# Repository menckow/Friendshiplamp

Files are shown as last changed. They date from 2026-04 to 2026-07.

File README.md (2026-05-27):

# Friendship Lamp (V2.3 — Family Schema)

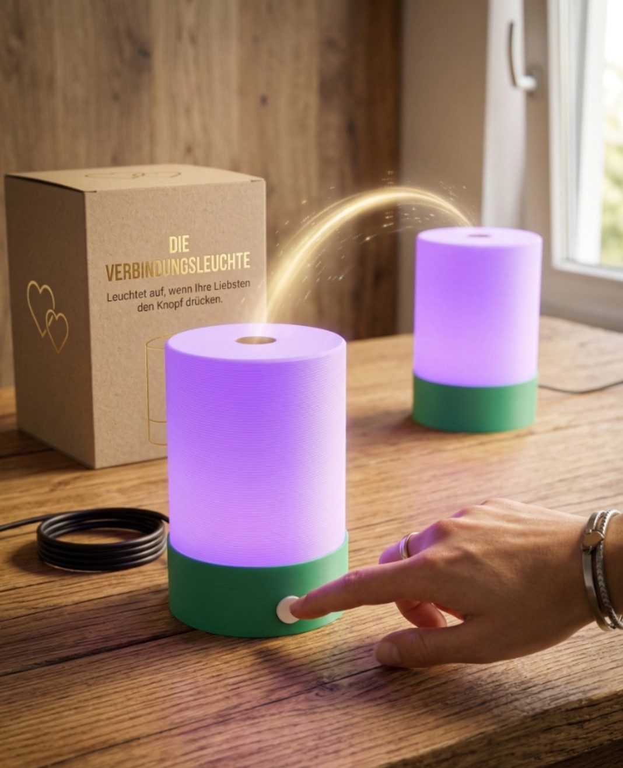
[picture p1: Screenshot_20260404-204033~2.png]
Friendship Lamp


The **Friendship Lamp** is an ESP32-based ambient light that connects friends through synchronized colors. When one person touches their lamp, all connected lamps across the world pulse in their unique identity color via MQTT.

Version **V2.3** introduces the **family circle schema (v2)** — a single lamp can belong to multiple family circles simultaneously, and the central Device Manager Dashboard groups all devices by family.

## 🚀 Key Features

*   **Modular Architecture**: Clean separation of hardware control, network logic, and configuration.
*   **Family Circles (v2 Schema)**: Configure one or more `Familienkreise` (comma-separated) per lamp. The lamp publishes button presses to every family it belongs to and receives signals from all of them. Multi-membership is supported.
*   **Source-Aware Signaling**: Each signal carries a `sender_type` field. Lamps ignore signals originating from boxes (so a box's motion sensor doesn't wake the lamp), while boxes show the lamp's color in a special complementary-LED mode when a lamp triggered the signal.
*   **Local Button Feedback**: Pressing the button lights the lamp itself in the identity color — visual confirmation that the press was registered, independent of the MQTT round-trip.
*   **Robust OTA Updates (two channels)**:
    *   **MQTT-triggered OTA**: per-device (`fl/device/<id>/update/trigger`), per-family (`fl/family/<f>/update/trigger/lamp`), or global (`fl/_global/update/trigger/lamp`). All with 32-character **MD5 validation** and dynamic LED progress bar.
    *   **Web Upload OTA**: Browse to the configuration page and upload a `.bin` directly; the lamp validates MD5 (optional), writes via chunked `Update.write()` and reboots automatically.
*   **Smart Security**: Built-in standard Root CA (ISRG Root X1) for seamless out-of-the-box support for HiveMQ and other secure public brokers—no manual certificate pasting required.
*   **Advanced Lighting Engine**: Smooth 32-bit gamma correction with effects like *Fade, Rainbow, Breathe, Fire, Comet,* and more.
*   **Intuitive Web Configuration & Remote Control**:
    *   **Captive Portal**: Mobile-friendly local portal for Wi-Fi setup, MQTT credentials, family-circle assignment, and hardware calibration.
    *   **Dedicated Web App**: A standalone modern [Web App](manager/Friendshiplamp_Web_App_V4_Final.html) for remote triggering of the lamp with custom color and **selectable effects** (Fade, Wipe, Chase, Rainbow, etc.).
*   **Smart Hardware Control**:
    *   **Capacitive Touch**: For On/Off and continuous brightness dimming.
    *   **Potentiometer**: Direct local color selection.
    *   **Button**: Sending the pulse color to friends.
*   **Night Mode (Do Not Disturb)**: NTP-synced, scheduled quiet hours configurable via the Web UI to keep the room completely dark and suppress incoming color flashes during sleep.

## 🛠️ Hardware Requirements

*   **Microcontroller**: ESP32 Dev Kit C or ESP32-S3.
*   **LEDs**: WS2812B (NeoPixel) Ring or Strip.
*   **Inputs**:
    *   1x Potentiometer (Analog)
    *   1x Momentary Button
    *   1x Capacitive Touch sensor (or a simple wire to a touch pin)

### Default Pinout (Configurable)

| Component | ESP32 Pin |
| --- | --- |
| NeoPixel DIN | GPIO 13 |
| Potentiometer Signal| GPIO 34 |
| Send Button | GPIO 4 |
| Touch Sensor | GPIO 32 |

## 💻 Setup & Installation

### 1. Build & Upload
This project is professionally managed using **PlatformIO**. 
1.  Clone the repository.
2.  Open the folder in VS Code with the PlatformIO extension installed.
3.  Click **Build** and then **Upload**.

### 2. First-Time Configuration
1.  If no Wi-Fi is configured, the lamp will pulse **purple** and open a Wi-Fi hotspot named `Freundschaftslampe-Setup`.
2.  Connect to the hotspot (Password: `12345678`).
3.  Your browser should open `http://192.168.4.1` automatically.
4.  Enter your home Wi-Fi details and MQTT broker credentials.
    *   *Tip: If using HiveMQ, simply check the "Use Standard Root-CA" box.*
5.  **Enter Family Circles** (comma-separated list, e.g. `schmidt,lieblings`). The lamp will subscribe to one signal topic per family and fan out its own button presses to all of them. Whitespace and case are normalized automatically.

## 📡 MQTT Integration & Monitoring

The project works with a central [Device Manager Dashboard](manager/dashboard_secure.html), which groups all devices by family circle and shows a green `v2` pill next to family-aware devices.

### Topic schema (v2)

| Purpose | Topic | Retained |
|---|---|---|
| Family signal (publisher + subscriber) | `fl/family/<familyId>/signal` | no |
| Device status (JSON) | `fl/device/<deviceId>/status` | **yes** |
| OTA per single device | `fl/device/<deviceId>/update/trigger` | no |
| OTA per family (lamps only) | `fl/family/<familyId>/update/trigger/lamp` | no |
| Global emergency OTA (lamps only) | `fl/_global/update/trigger/lamp` | no |
| OTA progress backchannel | `fl/device/<deviceId>/update/status` | no |

### Status payload (retained JSON)

```json
{
  "type": "lamp",
  "fw": "V2.3.0",
  "state": "online",
  "color": "#FFAA00",
  "families": ["schmidt", "lieblings"]
}
```

### Signal payload (on button press)

```json
{
  "client_id": "Schmidt-Wohnzimmer",
  "sender_type": "lamp",
  "color": "#FFAA00",
  "effect": "fade",
  "duration": 30000,
  "ts": 1716729600
}
```

The receiving devices apply a **self-filter** (ignore messages where `client_id` matches their own ID, important for multi-family membership) and an **NTP age filter** (older than 60 seconds → ignored, to prevent retained messages from re-triggering after reconnect).

### OTA payload

```json
{
  "url": "https://your-server.com/firmware.bin",
  "version": "V2.3.1",
  "md5": "b3e3e3b3e3e3b3e3e3b3e3e3b3e3e3b3",
  "target_type": "lamp"
}
```

`target_type` is optional defense-in-depth — devices verify it matches their own type before accepting the update.

### Web Upload OTA

Open the lamp's configuration page and use the **Firmware-Update** section to upload a `.bin` file directly. The lamp validates MD5 (optional 32-char hex), writes the firmware, and reboots automatically. The dashboard sees status changes via MQTT during the upload.

## 📄 License & Credits
Developed for the community. Feel free to fork and enhance!

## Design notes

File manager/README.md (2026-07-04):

# Manager — Browser-basierte Tools

In diesem Verzeichnis liegen zwei eigenständige HTML-Werkzeuge, die direkt im Browser laufen — kein Webserver, keine Installation. Beide Dateien öffnest Du per Doppelklick oder hostest sie statisch (z.B. GitHub Pages).

| Datei | Zweck |
|---|---|
| [`dashboard_secure.html`](dashboard_secure.html) | **Device Manager Dashboard** — zentrale Übersicht aller Lampen + Boxen, gruppiert nach Familienkreis, mit OTA-Steuerung. |
| [`Friendshiplamp_Web_App_V4_Final.html`](Friendshiplamp_Web_App_V4_Final.html) | Standalone-Remote für eine einzelne Lampe — Farbe und Effekt manuell auslösen. |

---

## 📊 Device Manager Dashboard

`dashboard_secure.html` ist die Leitstelle für alle Geräte in Deiner MQTT-Topologie. Es verbindet sich per **MQTT-over-WebSockets (TLS)** mit Deinem Broker und abonniert sowohl das alte v1-Schema als auch das neue v2-Familien-Schema parallel — Du siehst also Bestand und migrierte Geräte gleichzeitig.

### Login

Beim Öffnen erscheint eine Login-Maske. Trage ein:

* **MQTT Broker** — z.B. `xxx.s1.eu.hivemq.cloud` (ohne `wss://`, ohne Trailing-Slash)
* **Port** — `8884` für HiveMQ Cloud WebSockets (`8883` wird automatisch zu `8884` korrigiert, weil Browser TCP-MQTT nicht direkt sprechen können)
* **Username / Passwort** — die MQTT-Credentials Deines Brokers

Broker, User und Port werden für den nächsten Besuch im `localStorage` gespeichert. Das **Passwort nicht** — es bleibt nur in der Sitzung.

### Geräteliste

Sobald die Verbindung steht, abonniert das Dashboard:

* `+/status/#` (altes v1-Schema, z.B. `freundschaftslampe/status/<id>` und `zwitscherbox/status/<id>`)
* `fl/device/+/status` (v2-Schema mit JSON-Payload)
* `fl/device/+/update/status` (v2-OTA-Backchannel)

Jede empfangene Status-Nachricht wird zur Tabelle zugefügt oder aktualisiert. Geräte erscheinen **gruppiert nach Familienkreis** — v2-Geräte landen in der Gruppe ihrer im Payload genannten `families`, mehrfach falls in mehreren Kreisen. Geräte ohne Familienzuordnung (alle v1-Geräte und v2-Geräte ohne `families[]`) landen in der Sammelgruppe **„Bestand (altes Schema, ohne Familienzuordnung)"**.

Jede Gerätezeile zeigt:

| Spalte | Bedeutung |
|---|---|
| ID | Identitätsfarbe als Kreis + Client-ID + Schema-Pille (grün `v2` oder gelb `v1`) |
| Typ | `Lampe`, `Box (V6)`, `Box (A1S)` oder `Box (v1)`. Die beiden Box-Varianten brauchen unterschiedliche Firmware-Binaries — der Typ ergibt sich aus dem `type`-Feld der Status-JSON (`lamp`, `box`, `box-a1s`). |
| Version | Firmware-Version aus `fw` (v2) bzw. erstem Feld des `:`-Payload (v1) |
| Status | `online` / `offline` / Update-Status (gelb hinterlegt wenn `update` im Text) |
| Aktion | **Update**-Button für Einzelgerät |

### OTA-Karten

Im Grid unter der Tabelle gibt es vier Update-Karten:

| Karte | Zielgruppe | Topic |
|---|---|---|
| **Update: Lampen (v1)** | Alle v1-Lampen | `freundschaftslampe/update/trigger` |
| **Update: Zwitscherboxen (v1)** | Alle v1-Boxen | `zwitscherbox/update/trigger` |
| **Update: Pro Familie (v2)** | Lampen, V6-Boxen oder A1S-Boxen einer Familie | `fl/family/<id>/update/trigger/<type>` |
| **Update: Globaler Notfall-Push (v2)** | Alle Lampen, V6-Boxen oder A1S-Boxen | `fl/_global/update/trigger/<type>` |

`<type>` ist `lamp`, `box` (V6) oder `box-a1s` (A1S). Die drei Geräte-Typen brauchen unterschiedliche Firmware-Images — deshalb gibt es bewusst kein „Alles auf einmal", sondern einen Typ-Selektor in jeder Karte. Das Familien-Dropdown füllt sich automatisch aus den gesehenen Geräten — also: wenn keine Familie in der Liste, hat noch keine v2-Box/-Lampe sich gemeldet.

Jeder Update-Vorgang fragt vorher per Modal um Bestätigung und zeigt das tatsächlich verwendete Topic an.

### Einzel-Update

Klick auf **Update** in einer Gerätezeile öffnet die Bestätigung. Das Topic wird schema-bewusst gewählt:

* **v2-Geräte** → `fl/device/<id>/update/trigger`
* **v1-Lampen** → `freundschaftslampe/update/trigger/<id>` (Per-Device-Topic, das die migrierte Lampen-FW seit der ersten Phase abonniert)
* **v1-Boxen** → `zwitscherbox/update/trigger` mit `target: <id>` im Payload (Broadcast-Filter, der seit jeher auch von alter Box-FW respektiert wird — daher universell kompatibel)

Die URL, Version und MD5 werden aus der passenden v1-Karte oder den Familien-/Global-Feldern gezogen.

### Payload-Format

Alle OTA-Triggers verwenden das gleiche JSON:

```json
{
  "url": "https://your-server.com/firmware.bin",
  "version": "V2.3.1",
  "md5": "b3e3e3b3e3e3b3e3e3b3e3e3b3e3e3b3"
}
```

Bei v1-Box-Einzel-Updates kommt zusätzlich `"target": "<deviceId>"` dazu, damit nur die adressierte Box updatet. Bei v2-Topics nicht nötig — das Topic adressiert direkt.

### Sicherheits-Tipp

Das Dashboard ist eine reine Client-HTML — alle Credentials und Befehle laufen über Deinen Browser zum MQTT-Broker. Wenn Du das auf einem öffentlich erreichbaren Server hostest:

* Stelle sicher, dass nur autorisierte Personen Zugriff haben (z.B. via Reverse-Proxy mit Basic Auth).
* Nutze einen MQTT-User mit ACLs, die nur auf die nötigen Topics zugreifen können.
* Der WebSocket geht über `wss://` (TLS) — der Broker muss das unterstützen (HiveMQ Cloud tut das).

---

## 💡 Standalone Lamp Remote

`Friendshiplamp_Web_App_V4_Final.html` ist ein simples Remote-Frontend für eine **einzelne** Lampe. Du wählst Farbe, Effekt und Dauer, und das Tool publisht einen einzelnen Signal-Payload an das Signal-Topic. Nutzbar als „Lampe ohne Button" — z.B. wenn Du jemandem aus der Ferne ein bestimmtes Licht-Signal schicken willst.

Hinweis: Dieses Werkzeug stammt aus der v1-Ära und schreibt aktuell ans alte `mqttTopic`. Für v2 müsste es entsprechend auf `fl/family/<id>/signal` umgestellt werden — das ist noch nicht passiert. Wenn Du das brauchst, sag Bescheid, dann ziehen wir das Tool ebenfalls nach.

---

## Lokal öffnen vs. hosten

Beide HTML-Dateien sind self-contained (CDN-Abhängigkeit: `mqtt.js` für WebSocket-MQTT). Du kannst sie:

* **Doppelklicken** und im Browser direkt benutzen — funktioniert für die meisten modernen Browser.
* **Statisch hosten** (GitHub Pages, Caddy, Nginx, ein S3-Bucket usw.) — empfohlen, wenn Du sie öfter brauchst, weil sich Bookmarks/`localStorage` so sauber zuordnen lassen.

Kein Build-Schritt nötig.

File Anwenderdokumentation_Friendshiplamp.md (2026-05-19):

# 🌟 Freundschaftslampe — Anwenderdokumentation

**Version 2.2** · Stand: 2026-05

Diese Lampe verbindet dich über das Internet mit deinen Liebsten. Wenn du sie berührst und auf den Senden‑Knopf drückst, leuchten die verbundenen Lampen weltweit in deiner persönlichen Farbe auf — und umgekehrt.

---

## Inhalt

1. [Lieferumfang & Hardware-Übersicht](#1-lieferumfang--hardware-übersicht)
2. [Statusfarben (was die Lampe dir sagt)](#2-statusfarben-was-die-lampe-dir-sagt)
3. [Erstinbetriebnahme](#3-erstinbetriebnahme-schritt-für-schritt)
4. [Bedienung im Alltag](#4-bedienung-im-alltag)
5. [Konfigurations-Referenz (Webinterface)](#5-konfigurations-referenz-webinterface)
6. [Lichteffekte](#6-lichteffekte)
7. [Ruhemodus / Nicht stören](#7-ruhemodus--nicht-stören)
8. [Sicherheit (Admin-Passwort & TLS)](#8-sicherheit-admin-passwort--tls)
9. [Dashboard & OTA-Updates](#9-dashboard--ota-updates)
10. [Werkseinstellungen / Reset](#10-werkseinstellungen--reset)
11. [Troubleshooting](#11-troubleshooting)

---

## 1. Lieferumfang & Hardware-Übersicht

Eine vollständige Freundschaftslampe besteht aus:

| Komponente | Beschreibung |
|---|---|
| **ESP32 Dev Kit C** | Der "Kopf" der Lampe — WLAN-fähiger Mikrocontroller |
| **WS2812B / NeoPixel Ring** | Der Leuchtring (typisch 16, 24 oder 40 LEDs) |
| **Touch-Pad** | Eine kapazitive Fläche oder ein Draht an GPIO 32 |
| **Drehregler (Potentiometer)** | Für die lokale Farbauswahl |
| **Taster** | Zum Senden eines Signals |
| **Netzteil** | 5 V, mindestens 2 A empfohlen |
| **3D-gedrucktes Gehäuse** | siehe `lamp/Freundschaftslampe.stl` |

### Standard-Pinbelegung

| Funktion | ESP32-Pin |
|---|---|
| NeoPixel Daten (DIN) | GPIO 13 |
| Potentiometer (Signal) | GPIO 34 |
| Senden-Taster | GPIO 4 |
| Touch-Sensor | GPIO 32 |

> Hinweis Hardware: Für eine stabile Versorgung empfiehlt sich ein **Stützkondensator (≥ 470 µF)** parallel zur 5‑V‑Versorgung des LED‑Rings und ein **Vorwiderstand (~330–470 Ω)** seriell in der Datenleitung zwischen ESP32 und dem ersten Pixel. Beides ist im aktuellen Aufbau bereits vorgesehen.

---

## 2. Statusfarben (was die Lampe dir sagt)

| Lichtmuster | Bedeutung |
|---|---|
| 🟣 **Violett/Lila pulsierend** | Setup‑Modus: kein WLAN konfiguriert oder Heim‑WLAN nicht erreichbar |
| ⚪ **Kurz aufleuchten beim Start** | Boot abgeschlossen, Lampe startet ihre Dienste |
| 🎨 **Farbpuls in fremder Farbe** | Du hast ein Signal von einer befreundeten Lampe empfangen |
| 💡 **Konstantes Leuchten in deiner Farbe** | Normalbetrieb, Lampe ist eingeschaltet |
| 🚫 **Komplett dunkel** | Lampe ist über Touch ausgeschaltet ODER Ruhemodus aktiv |
| 🟢 **Fortschrittsbalken um den Ring** | Firmware‑Update (OTA) läuft — bitte nicht ausschalten |

---

## 3. Erstinbetriebnahme (Schritt für Schritt)

### 3.1 Strom anschließen

1. Verbinde die Lampe per USB‑Kabel mit dem mitgelieferten 5‑V‑Netzteil.
2. Nach ca. 5 Sekunden sollte die Lampe **violett** pulsieren — das ist der Setup‑Modus.

### 3.2 Mit der Lampe verbinden

1. Öffne auf deinem Smartphone oder Computer die **WLAN‑Einstellungen**.
2. Wähle das Netzwerk **`Freundschaftslampe-Setup`**.
3. Gib das Passwort ein: **`12345678`**
4. Normalerweise öffnet sich automatisch ein Konfigurationsfenster (Captive Portal).
   Falls nicht: Browser öffnen und **`http://192.168.4.1`** aufrufen.

### 3.3 Heim-WLAN eintragen

1. Im Abschnitt **WLAN‑Einstellungen** auf „Verfügbare WLANs" klicken — die Lampe scannt automatisch die Umgebung.
2. Dein Heim‑WLAN auswählen oder die SSID manuell eintragen.
3. WLAN‑Passwort eingeben.

### 3.4 MQTT-Broker eintragen

MQTT ist der Nachrichtendienst, über den die Lampen miteinander sprechen. Du brauchst die Zugangsdaten zu einem MQTT‑Broker.

**Empfohlen für Einsteiger:** [HiveMQ Cloud](https://www.hivemq.com/) — kostenlos für kleine Mengen, TLS standardmäßig aktiv.

| Feld | Beispiel | Bemerkung |
|---|---|---|
| MQTT Broker | `xxx.s2.eu.hivemq.cloud` | Hostname ohne `https://` |
| MQTT Port | `8883` | bei TLS, sonst `1883` |
| MQTT mit TLS/SSL | ✅ aktiviert | Empfohlen |
| Standard Root‑CA nutzen | ✅ aktiviert | Funktioniert mit HiveMQ und allen Let's‑Encrypt‑Brokern |
| MQTT Client ID | `Tom-Wohnzimmer` | Eindeutiger Name dieser Lampe |
| MQTT Topic | `freundschaftslampe/familie-meier` | Gleiches Topic für alle Lampen, die einander erreichen sollen |
| Benutzername / Passwort | (deine HiveMQ-Credentials) | |

> Wichtig: **Alle Lampen, die sich gegenseitig anleuchten sollen, müssen dasselbe Topic verwenden.**

### 3.5 Identität festlegen

Im Abschnitt **Lampen‑Einstellungen**:

* **Anzahl LEDs** auf den realen Wert deines Rings setzen (z. B. `16`, `24` oder `40`).
* **Touch‑Empfindlichkeit** vorerst auf `40` lassen (Standardwert).
* **Identitätsfarbe** wählen — diese Farbe sehen deine Freunde, wenn du ein Signal sendest.
* **Lichteffekt** wählen (siehe Kapitel 6).
* **Anzeigedauer** in Sekunden setzen (Standard: 10 s).

### 3.6 Admin-Passwort setzen

Im obersten Abschnitt **Administrator** trägst du ein **Webinterface-Passwort** ein. Dieses brauchst du später, wenn du die Lampe von deinem Heim‑WLAN aus konfigurieren willst. Lässt du das Feld leer (oder schreibst `none`), ist das Webinterface ohne Passwort erreichbar.

### 3.7 Speichern & Neustarten

Klicke unten auf **Speichern & Neustarten**.

* Die Lampe trennt das Setup‑Netzwerk und startet neu.
* Nach erfolgreichem Verbinden ist das violette Pulsieren weg.
* Sie ist nun bereit. 🎉

---

## 4. Bedienung im Alltag

### 👆 Touch-Sensor — Ein/Aus & Helligkeit

| Geste | Funktion |
|---|---|
| **Kurz tippen** (< 1 s) | Lampe **ein/aus** schalten |
| **Lang halten** (> 1 s) | **Helligkeit** stufenlos dimmen. Loslassen, wenn die Wunschhelligkeit erreicht ist. Bei der nächsten langen Berührung läuft die Richtung umgekehrt. |

> Spürt die Lampe deine Berührung nicht oder löst sie von allein aus? Siehe Abschnitt [Touch-Empfindlichkeit kalibrieren](#touch-empfindlichkeit-kalibrieren).

### 🎛️ Drehregler — Lokale Farbe

* Solange die Lampe **an** ist, kannst du am Drehregler deine *lokale* Leuchtfarbe ändern.
* Diese Farbe wird automatisch als deine **Identitätsfarbe** verwendet, wenn du das nächste Mal ein Signal sendest.

### 🔘 Senden-Taster — Gruß verschicken

* Einmal kurz drücken → die Lampe schickt ein Signal mit deiner aktuellen Farbe, dem gewählten Effekt und der eingestellten Dauer über MQTT raus.
* Alle Lampen, die dasselbe Topic abonniert haben, leuchten in deiner Farbe auf.

### 💌 Signal empfangen

Wenn jemand seine Lampe drückt:

1. Deine Lampe **unterbricht ihren aktuellen Zustand** und leuchtet in der Farbe des Senders.
2. Der eingestellte Effekt (Fade, Komet, …) läuft für die vom Sender festgelegte Dauer (Standard: 10 s).
3. Danach **kehrt deine Lampe automatisch in den vorherigen Zustand zurück** (aus = bleibt aus, an = leuchtet wieder in deiner Farbe).

---

## 5. Konfigurations-Referenz (Webinterface)

Erreichbar im Heim‑WLAN unter der IP, die dein Router der Lampe zugewiesen hat (z. B. `http://192.168.1.42`). Login: `admin` + dein Webinterface‑Passwort.

### Administrator

| Feld | Bedeutung |
|---|---|
| **Webinterface Passwort** | Schützt das Konfigurationsmenü. Leer oder `none` = kein Passwort. |

### WLAN-Einstellungen

| Feld | Bedeutung |
|---|---|
| **Verfügbare WLANs** | Live‑Scan; Auswahl füllt SSID automatisch aus |
| **WLAN SSID** | Name deines Heim‑WLANs |
| **WLAN Passwort** | Dazugehöriges Passwort |

### MQTT-Einstellungen

| Feld | Bedeutung |
|---|---|
| **MQTT Broker** | Hostname des Brokers |
| **MQTT Port** | `1883` (unverschlüsselt) oder `8883` (TLS) |
| **MQTT mit TLS/SSL** | Verschlüsselt aktivieren |
| **Standard Root‑CA nutzen** | ISRG Root X1 ist eingebaut → funktioniert mit HiveMQ & Let's Encrypt |
| **Eigenes CA Zertifikat** | Nur falls dein Broker ein anderes CA verwendet |
| **MQTT Client ID** | Eindeutige Kennung dieser Lampe |
| **MQTT Topic** | Gemeinsames Topic aller verbundenen Lampen |
| **Benutzername / Passwort** | Zugangsdaten zum Broker |

### Lampen-Einstellungen

| Feld | Bedeutung |
|---|---|
| **Anzahl LEDs** | Anzahl der WS2812B-Pixel im Ring |
| **Touch-Empfindlichkeit** | Schwellenwert (1–100). **Niedriger = unempfindlicher** (eher gegen Fehlauslösungen) |
| **Identitätsfarbe** | Deine persönliche Farbe |
| **Lichteffekt** | Animation (siehe Kapitel 6) |
| **Anzeigedauer** | Wie lange ein empfangenes Signal leuchtet (Sekunden) |

### Ruhemodus

| Feld | Bedeutung |
|---|---|
| **Aktivieren** | Eingehende Signale werden in einem Zeitfenster ignoriert |
| **Startzeit / Endzeit** | Stunde (0–23). Zeiträume über Mitternacht (z. B. 22 → 6) werden korrekt erkannt. |

---

## 6. Lichteffekte

| Effekt | Beschreibung |
|---|---|
| **Fade** | Sanftes Ein- und Ausblenden — der Klassiker |
| **Color Wipe** | Die Farbe „wischt" sich LED für LED um den Ring auf |
| **Theater Chase** | Wandernder Lauflicht‑Effekt |
| **Rainbow** | Volles Farbspektrum als Lauflicht (ignoriert deine Identitätsfarbe) |
| **Breathe** | Ruhiges, gleichmäßiges Pulsieren |
| **Feuer** | Dynamisches Flackern in deiner Farbe |
| **Komet** | Heller Punkt mit Schweif zieht um den Ring |

---

## 7. Ruhemodus / Nicht stören

Damit dich die Lampe nachts nicht weckt:

1. Im Webinterface den **Ruhemodus aktivieren**.
2. Start- und Endzeit setzen, z. B. **22 → 06**.
3. In diesem Zeitraum werden eingehende Signale **stillschweigend verworfen** — die Lampe bleibt komplett dunkel.

> Hinweis: Der Ruhemodus benötigt die per NTP synchronisierte Uhrzeit. Direkt nach Stromanschluss (Sekunden) ist diese noch nicht verfügbar — in dieser Phase werden Signale ohnehin sicherheitshalber ignoriert.

---

## 8. Sicherheit (Admin-Passwort & TLS)

* **Admin‑Passwort:** Im Heim‑WLAN ist das Webinterface durch HTTP‑Basic‑Auth geschützt. Setze ein starkes Passwort, sobald die Lampe online ist.
* **MQTT‑TLS:** Wenn deine Lampe über das Internet kommuniziert (z. B. HiveMQ Cloud), **immer TLS aktivieren**. Andernfalls könnten Dritte deine Signale mitlesen oder fälschen.
* **Topic:** Wähle ein nicht zu erratendes Topic — z. B. `freundschaftslampe/familie-meier-7c4f`, nicht nur `lampe`.

---

## 9. Dashboard & OTA-Updates

Wenn du mehrere Lampen verwaltest, gibt es ein zentrales Dashboard:

* **Datei:** `manager/dashboard_secure.html` lokal im Browser öffnen.
* **Live‑Status:** Alle Lampen werden mit Farbe, Firmware‑Version und Online/Offline angezeigt (Erkennung dank LWT).
* **OTA‑Updates:** Neue Firmware kann zentral per MQTT‑Befehl auf alle Lampen verteilt werden. Während des Updates läuft ein grüner Fortschrittsbalken um den Ring. Die Lampe prüft die MD5‑Summe der neuen Firmware — bei Fehler springt sie automatisch auf die alte Version zurück (Rollback‑Schutz).

---

## 10. Werkseinstellungen / Reset

Falls du WLAN-Daten oder das Admin‑Passwort vergessen hast:

**Variante A — über das Webinterface (wenn noch erreichbar):**
1. Felder für SSID + Passwort leeren, speichern.
2. Nach Neustart pulsiert die Lampe wieder violett (Setup‑Modus).

**Variante B — Firmware komplett neu flashen:**
1. Lampe per USB anschließen.
2. In VS Code mit PlatformIO: **Erase Flash** ausführen, dann neu Build & Upload.
3. Beim nächsten Start ist die Lampe wieder im Setup‑Modus.

---

## 11. Troubleshooting

### Lampe pulsiert dauerhaft violett

→ Sie kann das konfigurierte WLAN nicht erreichen. Prüfen:
* Stimmt die SSID exakt (Groß-/Kleinschreibung)?
* Ist das WLAN ein 2,4‑GHz‑Netz? **Der ESP32 unterstützt kein 5 GHz.**
* Ist die Signalstärke am Standort ausreichend?

### Lampe verbindet WLAN, aber empfängt keine Signale

→ MQTT‑Problem. Prüfen:
* Sind alle Lampen mit demselben **Topic** verbunden?
* Bei TLS: ist „Standard Root‑CA" aktiviert?
* Stimmen Benutzername/Passwort des Brokers?
* Sind die Lampen im Dashboard als `online` gelistet?

### Lampe geht zufällig an/aus oder flackert

Mögliche Ursachen, in der Reihenfolge der Wahrscheinlichkeit:

1. **Touch zu empfindlich** → Im Webinterface den Wert **Touch‑Empfindlichkeit** *verringern* (z. B. von 40 auf 25). Das macht den Sensor unempfindlicher gegen Störungen.
2. **Netzteil zu schwach / Datenleitung gestört** → Stützkondensator (≥ 470 µF) parallel zur 5‑V‑Versorgung des Rings und Vorwiderstand (~330 Ω) seriell in der NeoPixel‑Datenleitung einbauen.
3. **Direkt nach Stromanschluss** kurzes Aufleuchten in fremder Farbe → Das war eine *retained MQTT‑Message*; die aktuelle Firmware ignoriert diese, bis die Uhrzeit per NTP synchronisiert ist (wenige Sekunden).
4. **Drehregler verursacht Farb‑Flackern** → Mechanisch fest setzen und Lampe gegen Vibration sichern.

### Touch-Empfindlichkeit kalibrieren

* **Wert zu hoch** (z. B. 80): Lampe reagiert schon bei Annäherung oder von allein → **Wert senken** (z. B. 25–30).
* **Wert zu niedrig** (z. B. 10): Lampe reagiert nicht oder nur sehr verzögert → **Wert leicht erhöhen** (z. B. 35–45).
* Nach jeder Änderung das Webinterface speichern; die Lampe übernimmt den Wert ohne Neustart.

### LED-Ring zeigt falsche Anzahl oder bleibt teilweise dunkel

→ **Anzahl LEDs** im Webinterface muss exakt der Anzahl im Ring entsprechen.

### Webinterface erfragt Passwort, ich kenne es nicht

→ Siehe [Werkseinstellungen / Reset](#10-werkseinstellungen--reset).

### Firmware-Update bricht ab

→ Lampe startet automatisch mit alter Firmware neu (Rollback). Erneut über das Dashboard auslösen. Bleibt der Fehler: WLAN‑Signal am Lampen‑Standort prüfen.

### Lampe friert ein / reagiert nicht mehr

→ Kurz vom Strom trennen (5 Sek warten) und wieder anschließen. Wenn das Problem regelmäßig auftritt: Versorgung mit einem stärkeren Netzteil (≥ 2 A) und stabiler Verkabelung prüfen.

---

## 📄 Lizenz & Support

Entwickelt für die Community. Quelltext und Issues unter dem Projekt‑Repository. Viel Freude und herzliche Grüße ✨

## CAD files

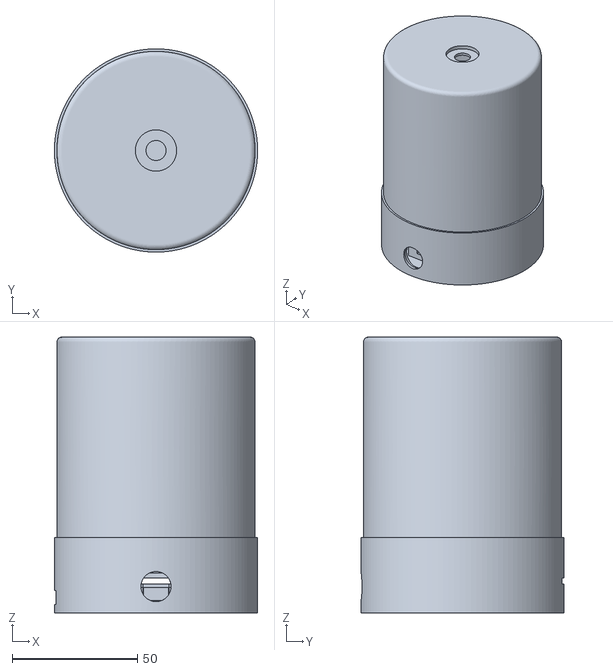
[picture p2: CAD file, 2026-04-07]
lamp/Freundschaftslampe.stl
81.0 x 81.0 x 110.0

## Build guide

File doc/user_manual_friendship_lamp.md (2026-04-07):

# User Manual: Friendship Lamp

Welcome to your new **Friendship Lamp**! This lamp allows you to stay connected with your loved ones over long distances by sending each other colorful light greetings.

Here is how you set up and operate your lamp.

---

## 1. Initial Setup (Wi-Fi Connection)

For the lamp to send and receive greetings, it needs to be connected to your Wi-Fi network.

1. **Recognizing Setup Mode:** If the lamp **lights up purple** when turned on, it couldn't find an existing Wi-Fi connection. It is now in setup mode (Access Point mode).
2. **Connecting to the Lamp:** Use a smartphone, tablet, or laptop and search for available Wi-Fi networks in your area. Connect to the network named **"Freundschaftslampe-Setup"**.
3. **Opening the Configuration Page:** Usually, a page opens automatically (the so-called Captive Portal). If this doesn't happen, simply open your web browser and enter any web address. You will now be redirected to the lamp's settings page.
4. **Entering Data:**
   - Under **WLAN-Einstellungen** (Wi-Fi Settings), enter the name (SSID) and password of your **home Wi-Fi**.
   - Under **MQTT-Einstellungen** (MQTT Settings), enter the connection details for the communication server (broker).
   - Under **Lampen-Einstellungen** (Lamp Settings), choose your personal **identity color** (this is the color that will light up on your partner's lamp when you send a greeting).
5. **Saving:** Click on **"Speichern & Neustarten"** (Save & Restart). The lamp will now restart and automatically connect to your home Wi-Fi. The purple light should now disappear.

---

## 2. Operating the Lamp

### 💡 Turning the Lamp On and Off
- **Short Touch:** Briefly tap the touch sensor to turn the lamp on or off.

### ☀️ Adjusting Brightness
- **Long Touch:** Keep your finger on the touch sensor to smoothly adjust the brightness. Release as soon as the light is bright or dim enough. With the next long press, the brightness will change in the opposite direction.

### 🎨 Customizing Your Local Color
- **Turning the Potentiometer (Knob):** When the lamp is turned on, you can turn the knob to set the local color of the light ring exactly to your liking.

### 💌 Sending a Colorful Greeting
- **Pressing the Button:** Press the button on the lamp once briefly. Your lamp will now send your previously set *identity color* over the internet. The connected lamp of your counterpart will light up that very second!

---

## 3. Receiving a Greeting

When someone presses the button on their lamp, the following happens on yours:
- Your lamp interrupts its current light and immediately lights up in the sender's color for **10 seconds**.
- After the 10 seconds have elapsed, the received light disappears again. The lamp completely automatically returns to the color and state (On or Off) it had before.

---

## 4. Quiet Mode (Do Not Disturb)

To ensure you aren't awakened at night by unexpectedly lighting up greetings, the lamp features a time control.

- You can enable the **Quiet Mode** (Ruhemodus) on the lamp's Wi-Fi setup page (see Step 1).
- Simply set a **Start Time** (e.g., 22:00 / 10 PM) and an **End Time** (e.g., 06:00 / 6 AM).
- During this period, incoming greetings are **ignored** by the lamp. The lamp will not light up.

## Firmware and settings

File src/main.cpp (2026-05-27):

#include <Arduino.h>
#include <ArduinoJson.h>
#include "ConfigManager.h"
#include "LampController.h"
#include "NetworkManager.h"
#include "MqttManager.h"
#include "InputHandler.h"
#include "OTAHandler.h"
#include "WebManager.h"
#include <time.h>

// == Globale Instanzen =====================================================
ConfigManager configMgr;
LampController lamp(40, 13); // Default values, will be updated in setup
NetworkManager network;
OTAHandler ota(lamp);
MqttManager mqtt(lamp, ota);
InputHandler input(lamp);
WebManager web(configMgr);

// == Hauptprogramm-Logik ==================================================
void setup() {
    Serial.begin(115200);
    Serial.println("Freundschaftslampe startet...");

    // 1. Konfiguration laden
    configMgr.begin();
    Config& config = configMgr.getConfig();

    // 2. Hardware initialisieren
    lamp.begin();
    input.begin(config);

    // 3. Netzwerk starten
    network.begin(config);
    
    // 4. Dienste (MQTT, Webserver)
    mqtt.begin(config);
    ota.setMqttManager(&mqtt);
    web.setLamp(&lamp);
    web.setMqtt(&mqtt);
    web.begin();

    Serial.println("System bereit.");
}

void loop() {
    Config& config = configMgr.getConfig();

    // Regelmäßige Updates der Module
    network.update();
    mqtt.update(config);
    input.update(config);
    lamp.update(config);

    // Button-Logik (Nachrichten senden) — v2-Schema: an alle Familien-Signale fanned-out.
    if (input.isButtonPressed()) {
        JsonDocument doc;
        doc["client_id"] = mqtt.getClientId(config);
        doc["sender_type"] = "lamp";
        char hexColor[8];
        sprintf(hexColor, "#%06X", config.identityColor);
        doc["color"] = hexColor;
        doc["effect"] = config.effect;
        doc["duration"] = config.duration;
        doc["ts"] = time(nullptr);

        String payload;
        serializeJson(doc, payload);

        auto families = mqtt.getFamilies(config);
        if (families.empty()) {
            Serial.println("Signal NICHT gesendet: keine Familien konfiguriert (Webkonfig pruefen).");
        } else {
            for (auto& fam : families) {
                String topic = "fl/family/" + fam + "/signal";
                mqtt.publish(topic.c_str(), payload.c_str());
                Serial.println("Signal gesendet -> " + topic);
            }
        }

        // Lokales LED-Feedback: bestaetigt den Druck visuell, auch wenn keine
        // Familie konfiguriert ist oder MQTT gerade nicht verbunden.
        lamp.startReceivedColorMode(config.identityColor, config.effect, config.duration);
    }

    // Neustart-Check
    if (web.shouldReboot()) {
        delay(1000);
        ESP.restart();
    }

    delay(10);
}

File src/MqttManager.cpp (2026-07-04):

#include "MqttManager.h"
#include <ArduinoJson.h>
#include "StandardCAs.h"
#include "OTAHandler.h"
#include <time.h>

MqttManager* MqttManager::_instance = nullptr;

MqttManager::MqttManager(LampController& lamp, OTAHandler& ota) : _client(_espClient), _lamp(lamp), _ota(ota) {
    _instance = this;
}

// --- v2 Helper -----------------------------------------------------------

std::vector<String> MqttManager::getFamilies(Config& config) {
    std::vector<String> result;
    String raw(config.familyIds);
    int start = 0;
    while (start <= (int)raw.length()) {
        int comma = raw.indexOf(',', start);
        String part = (comma < 0) ? raw.substring(start) : raw.substring(start, comma);
        part.trim();
        if (part.length() > 0) result.push_back(part);
        if (comma < 0) break;
        start = comma + 1;
    }
    return result;
}

String MqttManager::getFamiliesJsonArray(Config& config) {
    String out = "[";
    auto fams = getFamilies(config);
    for (size_t i = 0; i < fams.size(); i++) {
        if (i > 0) out += ",";
        out += "\"";
        out += fams[i];
        out += "\"";
    }
    out += "]";
    return out;
}

bool MqttManager::isFamilySignalTopic(const char* topic) {
    for (auto& t : _familySignalTopics) {
        if (strcmp(topic, t.c_str()) == 0) return true;
    }
    return false;
}

void MqttManager::begin(Config& config) {
    if (config.mqttTls) {
        if (config.useStandardCa) {
            _espClientSecure.setCACert(ISRG_ROOT_X1);
        } else if (strlen(config.mqttCaCert) > 0) {
            _espClientSecure.setCACert(config.mqttCaCert);
        } else {
            _espClientSecure.setInsecure();
        }
        _client.setClient(_espClientSecure);
    } else {
        _client.setClient(_espClient);
    }
    
    _client.setServer(config.mqttServer, config.mqttPort);
    _client.setCallback(MqttManager::staticCallback);
    // Default PubSubClient-Buffer ist 256 Bytes (Topic+Payload+Header). Fuer das
    // v2-JSON-Status-Topic mit families-Array reichen wir das auf 1024 hoch.
    _client.setBufferSize(1024);
}

void MqttManager::update(Config& config) {
    _config = &config;
    if (WiFi.status() == WL_CONNECTED) {
        if (!_client.connected()) {
            if (millis() - _lastMqttReconnectAttempt > RECONNECT_INTERVAL) {
                _lastMqttReconnectAttempt = millis();
                reconnect(config);
            }
        } else {
            _client.loop();
        }
    }
}

void MqttManager::loop() {
    _client.loop();
}

void MqttManager::forceReconnect(Config& config) {
    if (!_client.connected()) {
        reconnect(config);
    }
}

String MqttManager::getClientId(Config& config) {
    if (strlen(config.mqttClientId) > 0) return String(config.mqttClientId);
    uint64_t mac = ESP.getEfuseMac();
    return "Freundschaftslampe-" + String((uint32_t)(mac >> 32), HEX) + String((uint32_t)mac, HEX);
}

String MqttManager::getStatusTopic(Config& config) {
    return "fl/device/" + getClientId(config) + "/status";
}

void MqttManager::reconnect(Config& config) {
    String clientId = getClientId(config);
    String statusTopic = getStatusTopic(config);

    // LWT als JSON: state=offline. families mitgeben, damit das Dashboard die
    // Lampe beim Offline-Gang in derselben Familien-Gruppe anzeigen kann.
    char hexColor[10];
    sprintf(hexColor, "#%06X", config.identityColor);
    String lwt = String("{\"type\":\"") + DEVICE_TYPE_LAMP +
                 "\",\"fw\":\"" + FW_VERSION +
                 "\",\"state\":\"offline\"" +
                 ",\"color\":\"" + hexColor + "\"" +
                 ",\"families\":" + getFamiliesJsonArray(config) +
                 "}";

    bool connected = false;
    if (strlen(config.mqttUser) > 0) {
        connected = _client.connect(clientId.c_str(), config.mqttUser, config.mqttPassword, statusTopic.c_str(), 1, true, lwt.c_str());
    } else {
        connected = _client.connect(clientId.c_str(), statusTopic.c_str(), 1, true, lwt.c_str());
    }

    if (!connected) return;

    // --- v2 Subscribes ---------------------------------------------------
    // Familien-Signal- und Familien-OTA-Topics einsammeln, Bestandsliste ablegen.
    _familySignalTopics.clear();
    auto fams = getFamilies(config);
    for (auto& fam : fams) {
        String sig = "fl/family/" + fam + "/signal";
        String otaFam = "fl/family/" + fam + "/update/trigger/" + DEVICE_TYPE_LAMP;
        _client.subscribe(sig.c_str());
        _client.subscribe(otaFam.c_str());
        _familySignalTopics.push_back(sig);
    }
    // Per-Device-OTA (immer eindeutig)
    String otaDevice = "fl/device/" + clientId + "/update/trigger";
    _client.subscribe(otaDevice.c_str());
    // Globaler Notfall-Push fuer Lampen
    _client.subscribe("fl/_global/update/trigger/" DEVICE_TYPE_LAMP);

    // --- v2 Online-Status veroeffentlichen ------------------------------
    publishStatusV2(config, "online");

    // --- Migration-Hygiene: alten v1-Status-Topic einmalig leeren -------
    // (idempotent; nach Cutover bleibt das Dashboard sauber)
    String oldStatusTopic = "freundschaftslampe/status/" + clientId;
    _client.publish(oldStatusTopic.c_str(), "", true);

    Serial.println("MQTT verbunden (v2-Schema).");
    Serial.printf("  Familien: %u\n", (unsigned)fams.size());
    for (auto& fam : fams) Serial.println("    - " + fam);
}

void MqttManager::publishStatus(Config& config, const char* message) {
    // Legacy-Pfad: Erlaubt freie Statustexte, nutzt aber das v2-Topic.
    // Wir verpacken den Text als JSON-State, damit das Dashboard ihn parsen kann.
    publishStatusV2(config, message);
}

void MqttManager::publishStatusV2(Config& config, const char* state, const char* extra) {
    String clientId = getClientId(config);
    char hexColor[10];
    sprintf(hexColor, "#%06X", config.identityColor);

    String payload;
    payload.reserve(256);
    payload += "{\"type\":\"" DEVICE_TYPE_LAMP "\",";
    payload += "\"fw\":\""; payload += FW_VERSION; payload += "\",";
    payload += "\"state\":\""; payload += state; payload += "\",";
    payload += "\"color\":\""; payload += hexColor; payload += "\",";
    payload += "\"families\":"; payload += getFamiliesJsonArray(config);
    if (extra && *extra) {
        payload += ",\"info\":\""; payload += extra; payload += "\"";
    }
    payload += "}";

    String topic = getStatusTopic(config);
    _client.publish(topic.c_str(), payload.c_str(), true);
}

void MqttManager::publish(const char* topic, const char* payload, bool retained) {
    _client.publish(topic, payload, retained);
}

void MqttManager::staticCallback(char* topic, byte* payload, unsigned int length) {
    if (_instance) {
        _instance->callback(topic, payload, length);
    }
}
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

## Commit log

2026-03-30 docs: Add README.md with functionality description and wiring diagram
2026-04-07 fix(wifi): Implement connection timeout with AP mode fallback
    [main.cpp]
2026-04-07 docs: add documentation, 3D model, and English README
    This commit adds the user manual in German and English, the STL file for the lamp case, and appends the English translation to the README.md. It also updates the LED count in main.cpp and comments ou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
    [Freundschaftslampe.stl]
2026-04-07 Update: WebConfig Security, MQTT JSON, Interrupts, and NeoPixel config
2026-04-07 Docs: Update README with new security, JSON, and LED configurations
2026-04-07 Fix: AP Modal captive portal memory and auth failures
    [main.cpp]
2026-04-07 Fix: Set correct ESP32-S3 board in platformio.ini after reset
2026-04-08 Fix duplicate entries in README functionality section
    Removed duplicate entries for 'Secure Web-UI' and 'Dynamic LED Count' in the README.
2026-04-08 Webkonfiguration erweweitert. Unter anderem kann nun die Dauer der Anzeige der empfangenen Farbe eingestellt werden. Außerdem wird die Anzeige mit einem einfachen Effekt gestartet, anstatt sofort die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
2026-04-08 Fix: All lighting effects (except rainbow) now use the received identity color as basis
    [main.cpp]
2026-04-08 Fix: Integrated brightness scaling and serial debug for lighting effects
    [main.cpp]
2026-04-08 Fix: Added gamma32 correction and improved color scaling for lighting effects
    [main.cpp]
2026-04-09 Defaultwerte für die Lampe angepasst, damit sie nicht sofort mit voller Helligkeit und weißem Licht startet. Stattdessen startet sie jetzt ausgeschaltet.
2026-04-09 Fix: Ensure visibility of received colors even if lamp is locally off
    [main.cpp]
2026-04-09 Fix: Add certificate trimming and diagnostics for SSL OTA updates
    [main.cpp]
2026-04-09 Fix: Hardcode GitLab Root CA to bypass SSL formatting issues
    [main.cpp]
2026-04-09 Fix: Verified SSL Root CAs and robust URL detection for OTA
    [main.cpp]
2026-04-10 Fix: compilation errors (duplicate FW_VERSION and wrong bundle symbol)
    [main.cpp]
2026-04-10 Fix: resolve OTA SSL errors and 302 redirects by using Insecure mode and enabling FollowRedirects
    [main.cpp]
2026-04-10 Feature: Switch to static OTA topics and implement Version:ClientID status format
2026-04-10 Bugfix: Versionnummer in main.cpp aktualisiert
    [main.cpp]
2026-04-13 issues 2,3,4 resolved, commit message updated accordingly.
    [main.cpp]
2026-04-13 bugfix: Corrected logic error in main.cpp
    [main.cpp]
2026-04-15 Bugfixing MQTT connection issues and improving OTA update handling. Added support for standard CA certificates to enhance security. Updated web interface templates for better user experience. Refacto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
    [MqttManager.cpp, OTAHandler.cpp, WebManager.cpp]
2026-04-15 Bug fix: Update MQTT and OTA handling
    [MqttManager.cpp, OTAHandler.cpp]
2026-05-08 bug fix: Corrected MQTT topic subscription and message handling
    [MqttManager.cpp, main.cpp]
2026-05-15 bugfix - Fix MQTT connection issues and improve input handling
    [InputHandler.cpp, InputHandler.h, MqttManager.cpp]
2026-05-19 docs: Vollständige Anwenderdokumentation überarbeitet
    Komplette Neufassung mit Erstinbetriebnahme, Bedienung,
    Konfigurations-Referenz, Lichteffekten, Sicherheit und
    Troubleshooting-Abschnitten — inkl. Hinweisen zu Touch-
    Empfindlichkeit und Retained-MQTT-Verhalten.
2026-05-25 revert: Rollback Touch-/Loop-Änderungen von gestern (verursachten An/Aus-Problem)
    Die Änderungen aus 4815e8f (Pot-Deadband, BRIGHTNESS_ANIM_DELAY 10->25,
    setBrightness-Early-Return, delay(10) entfernt) verursachten wieder
    sporadisches Aufleuchten der Lampe. Rollback der vier Source-Dateien
    auf den Stand von d50069b (letzte Woche, getestet und stabil):
    - src/InputHandler.cpp
    - src/InputHandler.h
    - src/LampController.cpp
    - src/main.cpp
    Dashboard- und Doku-Änderungen (manager/, doc/, README.md) bleiben
    unangetastet. Ungestagete Dashboard- und MqttManager-Änderungen
    ebenfalls unverändert für separates Nachziehen.
    [InputHandler.cpp, InputHandler.h, main.cpp]
2026-05-25 feat: Per-Device OTA-Updates über Dashboard
    Dashboard sendet OTA-Trigger jetzt an gerätespezifisches Topic
    ({type}/update/trigger/{id}) statt Broadcast. Firmware abonniert
    zusätzlich zum Broadcast-Topic auch ihr eigenes Per-Device-Topic
    und verarbeitet Updates aus beiden Quellen.
    - manager/dashboard_secure.html: Trigger-Topic mit Geräte-ID
    - src/MqttManager.cpp: Subscribe + Callback für Per-Device-Topic
    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
2026-05-25 fix: LED-Flackern durch Potentiometer-Deadband eliminieren
    Bei eingeschalteter Lampe wurde alle 10ms der ADC am GPIO 34 gelesen
    und setColorHSV() aufgerufen. Das ADC-Rauschen (±20-50 LSB) reichte
    nach der Hue-Skalierung und gamma32()-Korrektur regelmäßig aus, um
    pixels.show() 50-100x pro Sekunde mit minimal abweichenden Farben
    auszulösen — sichtbar als leichtes Schimmern/Flackern.
    Fix (isoliert aus dem zurückgerollten Commit 4815e8f):
    - ADC-Read nur noch alle 50ms (POT_READ_INTERVAL)
    - Update nur wenn Hue-Änderung > 300 Schritte (POT_DEADBAND, ~0,5%)
    Touch-Logik, delay(10) im Loop und alle anderen Pfade unverändert.
    [InputHandler.cpp, InputHandler.h]
